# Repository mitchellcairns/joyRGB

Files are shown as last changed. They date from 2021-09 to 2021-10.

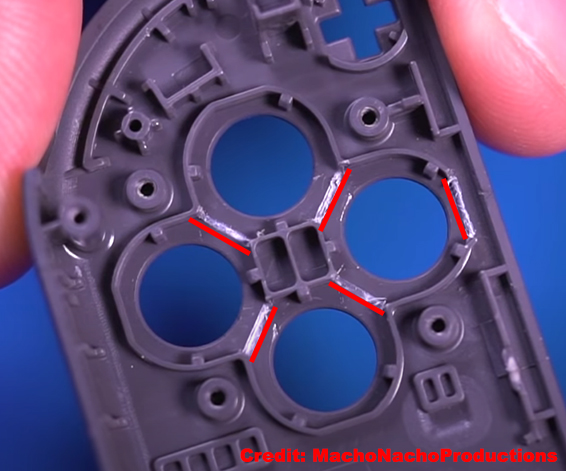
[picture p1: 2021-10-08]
diagrams/RightFrontShellTrim.jpg

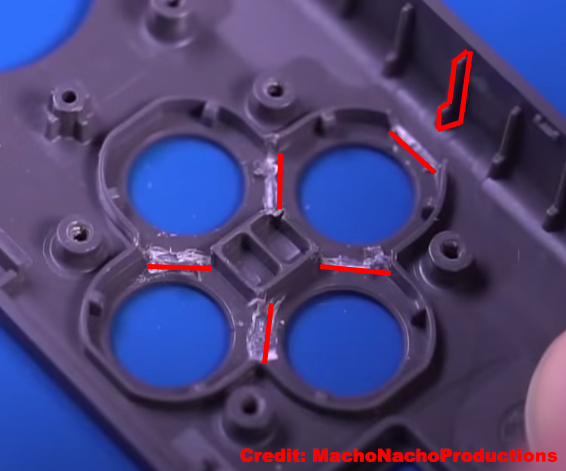
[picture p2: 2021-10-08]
diagrams/LeftFrontShellTrim.jpg

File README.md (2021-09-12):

# joyRGB
Joycon RGB LED kit

See the PDF for info on operating this kit

Features:
- Use the front buttons to control the LED kit
- Full RGB
- Use HEX/HTML Color codes to set up your own presets
- Ability to change color of buttons on the fly
- Rainbow mode
- Auto power on/off
- Brightness control

Install instructions:
- Part 1 - https://www.youtube.com/watch?v=M1x_yPTUGak
- Part 2 - https://www.youtube.com/watch?v=-7K7XvtfKoE
- Part 3 - https://www.youtube.com/watch?v=3CIYKLGDYLE

This Joycon RGB LED project allows the use of individually addressable LEDs to light up the buttons. It does require
trimming the shell, but the end result is a very clean install with little to no light bleed.

While I use hollowed out resin-cast buttons on installs, clear buttons from ExtremeRate will probably also work with some modification.

The rubber pad is replaced with a 3D printed bracket (STL file in this repo) for rigidity underneath the flex PCB. 
The gerber file should be manufactured fairly thin. There's a file for the hardener layer as well to support the pads underneath the
Attiny85 microcontroller.

See the bill of materials for all parts required.

The 10k ohm resistor is used in front of the transistor to control the 'Latch' line on the microcontroller for auto on-off functionality.
330 ohm resistor goes on the LED data line to smooth the signal.

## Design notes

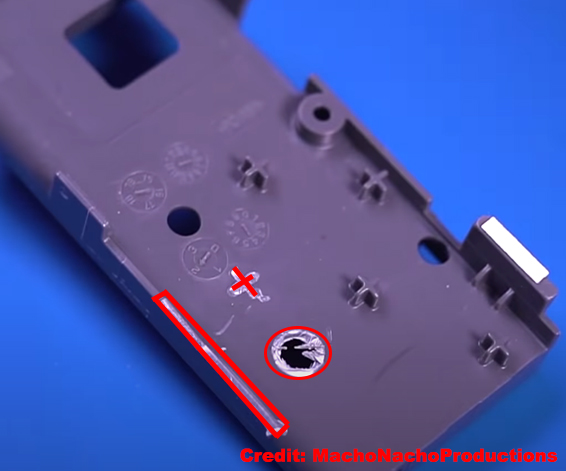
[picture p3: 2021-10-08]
diagrams/LeftTrayTrim.jpg

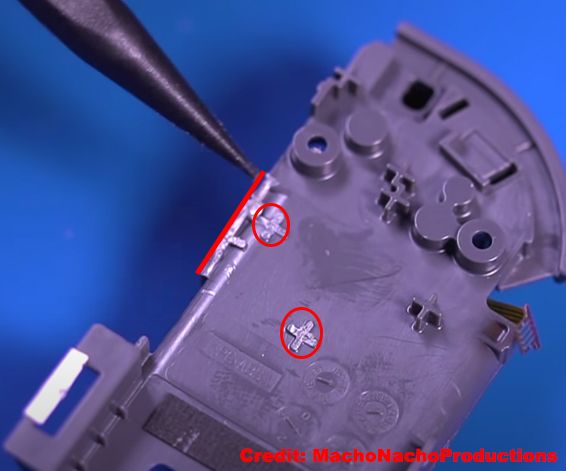
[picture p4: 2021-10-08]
diagrams/RightTrayTrim.jpg

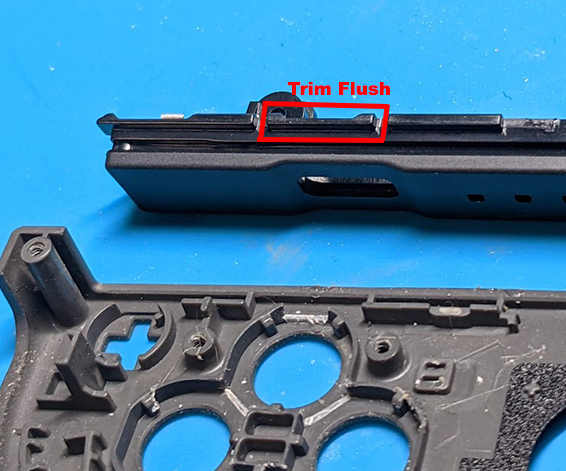
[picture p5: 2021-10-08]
diagrams/RightRailTrim.jpg

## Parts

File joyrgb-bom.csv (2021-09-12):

Item Link | Qty | Item Name
https://www.aliexpress.com/item/32878302621.html?spm=a2g0s.9042311.0.0.12ab4c4d19utiV | 8 | WS2812B-2020 (5mA variant)
https://www.aliexpress.com/item/1005003126067624.html | 2 | ATTINY85-20SU SOP-8
https://www.aliexpress.com/item/1005001436923851.html | 2 | 330 ohm 0603 SMT resistor
https://www.mouser.com/ProductDetail/279-CPF0805F10KC1 | 2 | 10k ohm 0603 SMT resistor
https://www.mouser.com/ProductDetail/78-BAV19WS-HG3-08 | 2 | General purpose Switching Diode SOD-323
https://www.mouser.com/ProductDetail/583-MMBT4401 | 2 | SOT23 NPN Transistor 0.6A 40V

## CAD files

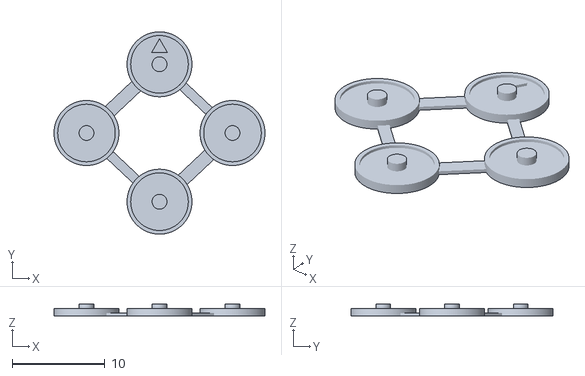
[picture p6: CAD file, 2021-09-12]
JoyconButtonBracket.stl
22.7 x 21.8 x 1.28

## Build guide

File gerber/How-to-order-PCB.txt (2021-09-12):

How to Order PCB

Please refer to:
https://docs.easyeda.com/en/PCB/Order-PCB

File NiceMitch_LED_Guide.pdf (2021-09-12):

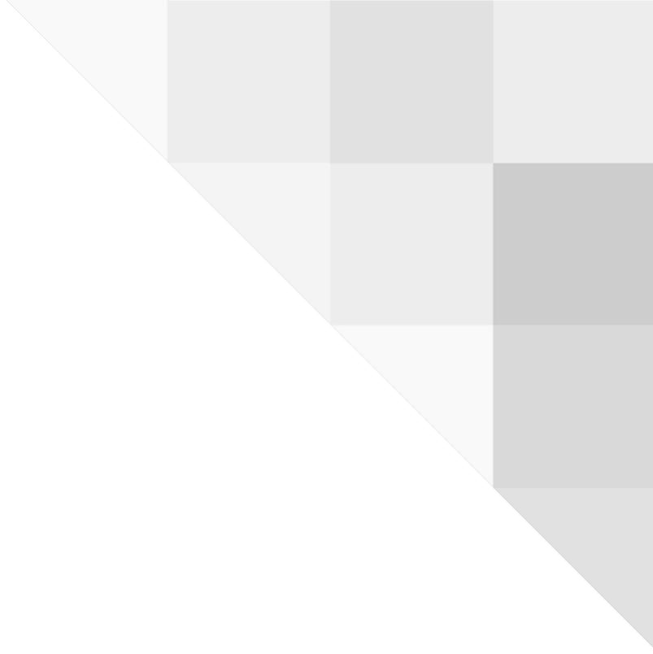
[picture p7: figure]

# Mitch’s JoyCon RGB Mod

# Product Guide

Last Updated July 6, 2021

# 1. Product Controls Overview

In all modes, this product is controlled by pressing a button combination on each JoyCon controller.

On the right JoyCon, this is done by holding the primary button, ‘Plus’, and pressing the secondary button, ‘X’.

On the left JoyCon, this is done by holding the primary button, ‘Minus’, and pressing the secondary button, ‘Up’.

There are two types of inputs-- presses and holds.

A press is performed by holding the primary button, then pressing the second button any number of times.

A hold is performed by holding the primary button, then pressing the second button any number of times, then holding the final press. Keep these directions in mind when reading the guide below and you will be successful in configuring/controlling the LEDs.

# 2. Color Modes

## A. Preset mode -- Built-in color presets B. Solid color mode -- A mode to simply display one color C. Rainbow fade mode -- A mode that fades between all colors continuously

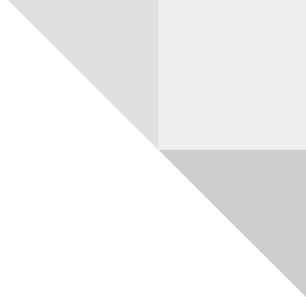
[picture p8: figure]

2

# 3. Device Modes and Controls

## A. Default mode

Upon receiving your JoyCons, the device will be in ‘default’ mode. Here are list of functions you can perform along with the required button inputs:

1. Turn LEDs on/off -- Double press and hold.
2. Decrease brightness -- Double press.
3. Increase brightness -- Triple press.
4. Color mode quick-change -- Triple press then hold.
a. This will cycle between color presets in the following order -- Preset modes, Solid color mode*, Rainbow fade mode.

*If you want to change the color shown in solid color mode, you will need to enter the advanced configuration mode first.

b. Between each color mode change, you will see the lights flash blue twice.
5. Enter advanced configuration mode -- Quadruple press. You will know you’ve entered advanced configuration mode when you see the lights flash teal twice.
6. Enable or Disable display mode -- Quadruple press then hold.
a. If you are enabling display mode, you will see the lights flash orange twice.
b. If the mode is being disabled, you will see the lights flash green twice.

## B. Advanced configuration mode

Depending on which color mode you are in, your configuration options and controls will vary. Please see the table below to understand the configuration options/controls for each color

3

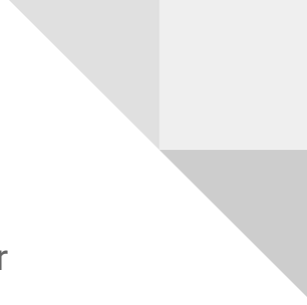
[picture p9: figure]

mode. In advanced configuration mode Press three times to cycle between each of the color modes below. Each time you cycle between a color mode the lights flash blue twice:

1. Preset mode
a. Cycle to the next built-in preset -- Single press.
2. Solid color mode
a. Increase color hue -- Single press.
b. Decrease color saturation -- Double press.
3. Rainbow fade mode
a. Increase color fade speed -- Single press. -- This option loops around after reaching the fastest speed.

In advanced configuration mode, four presses will take you to brightness configuration mode which is the final step before you can save your customizations. You will know you are entering brightness selection mode when you see the lights flash yellow twice.

## C. Brightness configuration mode

This mode simply lets you change the brightness. This is the final setting that needs to be modified before all settings can be saved to the onboard storage.

1. Decrease brightness -- Single press.
2. Increase brightness -- Double press.
3. Save all settings and reboot -- Quadruple press. You will know you have saved all settings when you see the lights flash white twice.

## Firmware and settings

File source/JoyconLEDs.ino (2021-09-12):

#include <FastLED.h>
#include "config.h"
#include <avr/sleep.h>
#include <avr/interrupt.h>
#include <EEPROM.h>

#define LED_COUNT 4
#define COLOR_TIME 50 // Time to fade between colors
#define CHECK_COUNT 5 // How many times to poll buttons for averages
#define BUTTON_THRESHOLD 45 // Value cutoff to determine if button is pressed or not (analog read)
byte SLOWEST_RAINBOW = 26;

// Button states setup
#define NO_PRESS 0
#define RELEASED_PRESS 1
#define HELD_PRESS 2

// Release state setup
#define HELD_START 200
#define HELD_ONE 201
#define HELD_TWO 202
#define HELD_THREE 203


// PIN setup
// ----------------
#define LED_PIN 0
#define aPin A3
#define yPin A2
#define ePin 2
// ----------------
// ----------------

byte SAV_DEBUG = 2;

// Button tracking
// ---------------
bool aPressed = false;
bool yPressed = false;
bool allPressed = false; // true if all buttons pressed
bool finishedHold = true; // Keep track of presses to prevent trailing inputs
byte aValue = 0; // Use to get a button value
byte yValue = 

0; // Use to get y button value
int timer = 0; // store the timer value when counting button presses
int buttonTime = 100; // timer cap
byte buttonPresses = 0; // how many times the button has been pressed
// ----------------
// ----------------

// Color/Brightness setting
// ----------------
byte brightness = 70; // led brightness

bool colorDirty = true; // Set true after changing modes!
bool colorSet = false; // Set true to start a fade!
bool colorInit = false; // Set true after changing and setting up your mode
float colorIncrement = 0; // Used to determine color fade increment (between 0 and 1)

byte colorStep = 15;         // Amount to step up when performing first color selection before going into fine

byte fadeTime = COLOR_TIME; // Time to fade between color ints (1 value at a time) for rainbow modes in ms
byte rainbowTime = 20;

CRGB lastLeds[LED_COUNT]; // Previous color values
CRGB leds[LED_COUNT]; // Current color values
CRGB nextLeds[LED_COUNT]; // Upcoming color values (when fading)
// ----------------
// ----------------

// Mode settings
// ----------------
byte configMode = 0;
#define DEFAULT_MODE    0
#define CONFIG_MODE     1   // Edit general configuration
#define BRIGHTNESS_MODE 2   // Edit brightness for all presets

bool enabled = true;
bool displayMode = true; // If display mode is ON, the LEDs will stay on. 

byte colorMode = 0;
#define COLOR_PRESET     0
#define COLOR_SOLID      1
#define COLOR_RAINBOW    2
byte colorModes = 3;

byte presetSelection = 0;

byte presetCount = 5;
CRGB presets[5][LED_COUNT] = {
  { CRGB::Yellow, CRGB::Green, CRGB::Blue, CRGB:: Red }, //SFC sideways right 
  { CRGB::Green, CRGB::Blue, CRGB::Red, CRGB::Yellow}, // SFC
  { 0xCBCBCB, 0xCBCBCB, 0x41C4C0, 0xEC1328}, // Gamecube - Gray, Gray, Teal, Red
  { 0xE96261, 0xF2CF1A, 0x62CBA1, 0x3E7CCB}, // Dreamcast
  { 0xFFC100, 0xFFC100, CRGB::MediumBlue, CRGB::Green}  // N64
};

CHSV rainbowColor = CHSV(0, 255, 255); // Start with red

UserPreference upref;

// ----------------
// ----------------

void setup() {
  // put your setup code here, to run once:
  delay(100);
  EEPROM.get(0, upref);
  delay(100);
  if (upref.saved == SAV_DEBUG) {
    brightness = upref.brightness;
    colorMode = upref.colorMode;
    rainbowTime = upref.rainbowTime;
    rainbowColor.hue = upref.hue;
    rainbowColor.saturation = upref.saturation;
    presetSelection = upref.presetSelection;
    displayMode = upref.displayMode;
  }
  
  ADMUX = 0x10010000; // Enable internal 2.56v reference
  // FastLED.addLeds<NEOPIXEL, LED_PIN>(leds, LED_COUNT);
  FastLED.addLeds<WS2812B, LED_PIN, RGB>(leds, LED_COUNT);
  FastLED.setBrightness(brightness);
  FastLED.show();

  pinMode(yPin, INPUT);
  pinMode(aPin, INPUT);
  pinMode(ePin, INPUT_PULLUP);
}

void loop() {

  byte butt = buttonCounter();

  idle(butt);

  FastLED.delay(CHECK_COUNT);

  if (!displayMode) {
    if (sleepCheck()) sleep(); // Check to see if we should sleep!
  }
  else {
    delayMicroseconds(400);
  }

}

byte buttonCounter() {

  if (buttonCheck(false) == RELEASED_PRESS) { // When a button is pressed what do we do?
    if (timer == 0 and buttonPresses == 0) { // If we haven't started a timer, lets add a button press and begin adding to the timer.
      timer += 1;
      buttonPresses = 1;
    }
    else if (timer < buttonTime) { // If we are still in the allotted timeframe, add another button press.
      buttonPresses += 1;
    }
  }

  if (timer > 0 and timer < buttonTime) { // If we're in a time loop, do the following
    timer += 1;
  }
  else if (timer >= buttonTime) { // What do we do if the timer is full? We reset the timer, return the button press count and reset that.
    byte toReturn = buttonPresses;
    if (buttonCheck(true) == HELD_PRESS){
      toReturn += HELD_START;
    }
    buttonPresses = 0;
    timer = 0;
    return toReturn;
  }

  // Default return 0
  return 0;
}

byte buttonCheck(bool timeOver) {
  smooth();

  if (aValue >= BUTTON_THRESHOLD) aPressed = true;
  else {
    aPressed = false;
    allPressed = false;
  }

  if (yValue >= BUTTON_THRESHOLD) yPressed = true;
  else {
    yPressed = false;
  }

  if (aPressed and yPressed and !allPressed) {
    allPressed = true;
  }
  else if (allPressed and !yPressed and finishedHold) {
    allPressed = false;
    return RELEASED_PRESS;
  }
  else if (!finishedHold and !yPressed){
    allPressed = false;
    finishedHold = true;
  }
  
  if (allPressed and timeOver) {
    allPressed = false;
    finishedHold = false;
    return HELD_PRESS;
  }

  return NO_PRESS;
}

bool sleepCheck() {
  bool shouldSleep = true;
  for (int i = 0; i < 4; i++){
    int returnValue = digitalRead(ePin);
    if (returnValue == LOW) shouldSleep = false;
  }

  return shouldSleep;
}

void smooth() { // Smooth read of values
  aValue = 0;
  yValue = 0;

  for (byte i = 0; i < CHECK_COUNT; i++) {
    int tempA = analogRead (aPin);
    tempA = analogRead(aPin);
    if ((tempA/4) > aValue) aValue = (tempA/4);
  }
  FastLED.delay(1);
  for (byte i = 0; i < CHECK_COUNT; i++) {
    int tempY = analogRead (yPin);
    tempY = analogRead(yPin);
    if ((tempY/4) > yValue) yValue = (tempY/4);
  }
  FastLED.delay(1);

  // Take an average of all the readings.
  //aValue = aValue / CHECK_COUNT;
  //yValue = yValue / CHECK_COUNT;

}

#define POWER_SWITCH      0
#define SATURATION_CHANGE 1
#define HUE_CHANGE        2
#define BRIGHTNESS_UP     3
#define BRIGHTNESS_DOWN   4
#define COLOR_MODE_CHANGE 5
#define RAINBOW_SPEEDUP   6
#define PRESET_CYCLE      7
#define ENABLE_BRIGHTNESS 11
#define SAVE_ALL          12
#define ENABLE_CONFIG     13
#define MODE_CYCLE        14
#define DISPLAY_MODE      15

void buttonFunction(byte in) {
  if (in == COLOR_MODE_CHANGE) {          // Switch color modes
    colorMode += 1;
    if (colorMode >= colorModes) colorMode = 0;
    if (upref.saved == SAV_DEBUG)
    {
      rainbowColor.hue = upref.hue;
      rainbowColor.saturation = upref.saturation;
    }
    switchIndicator(CRGB::Blue);
    resetColor(false);
  }
  else if (in == POWER_SWITCH) {          // Turn power on/off
    if (enabled) {
      for (byte i = brightness; i > 0; i--) {
        FastLED.setBrightness(i);
        FastLED.show();
        FastLED.delay(5);
      }
      FastLED.clear();
      FastLED.show();
      enabled = false;
    }
    else if (!enabled) {
      for(byte i = 0; i < LED_COUNT; i++) {
        leds[i] = lastLeds[i];
      }
      for (byte i = 1; i <= brightness; i++) {
        FastLED.setBrightness(i);
        FastLED.show();
        FastLED.delay(10);
      }
      enabled = true;
    }
  }
  else if (in == SATURATION_CHANGE) {     // Uptick the saturation
    rainbowColor.saturation -= 20;
    if (rainbowColor.saturation <= 0) rainbowColor.saturation = 255;
    resetColor(colorMode == COLOR_RAINBOW);
  }
  else if (in == HUE_CHANGE) {            // Uptick the hue
    rainbowColor.hue += 15;
    if (rainbowColor.hue >= 255) rainbowColor.hue = 0;
    resetColor(colorMode == COLOR_RAINBOW);
  }
  else if (in == BRIGHTNESS_UP) {         // Uptick brightness
    if (brightness + 20 <= 255) brightness += 20;
    FastLED.setBrightness(brightness);
    FastLED.show();
  }
  else if (in == BRIGHTNESS_DOWN) {       // Downtick brightness
    if (brightness - 20 >= 0) brightness -= 20;
    FastLED.setBrightness(brightness);
    FastLED.show();
  }
  else if (in == RAINBOW_SPEEDUP) {       // Uptick rainbow fade speed
    rainbowTime -= 2;
    if (rainbowTime <= 0) rainbowTime = SLOWEST_RAINBOW;
  }
  else if (in == PRESET_CYCLE) {          // Next item in presets
    presetSelection += 1;
    if (presetSelection >= presetCount) presetSelection = 0;
    resetColor(false);
  }
  else if (in == ENABLE_BRIGHTNESS) {     // Switch to brightness edit mode
    FastLED.setBrightness(brightness);
    FastLED.show();
    configMode = BRIGHTNESS_MODE;
    switchIndicator(CRGB::Yellow);
    resetColor(false);
  }
  else if (in == SAVE_ALL) {              // Save all settings to EEPROM
    upref.hue = rainbowColor.hue;
    upref.saturation = rainbowColor.saturation;
    upref.brightness = brightness;
    upref.colorMode = colorMode;
    upref.rainbowTime = rainbowTime;
    upref.saved = SAV_DEBUG;
    upref.presetSelection = presetSelection;
    upref.displayMode = displayMode;
    EEPROM.put(0, upref);
    delay(100);
    configMode = DEFAULT_MODE;
    switchIndicator(CRGB::White);
    resetColor(false);
  }
  else if (in == ENABLE_CONFIG) {
    configMode = CONFIG_MODE;
    switchIndicator(CRGB::Teal);
    resetColor(false);
  }
  else if (in == MODE_CYCLE) {
    if ( colorMode == COLOR_PRESET ) {
      presetSelection += 1;
      resetColor(false);
      if (presetSelection >= presetCount) 
      {
        presetSelection=0;
        buttonFunction(COLOR_MODE_CHANGE);
      }
    }
    else if ( colorMode == COLOR_SOLID ) {
      buttonFunction(COLOR_MODE_CHANGE);
    }
    else if ( colorMode == COLOR_RAINBOW ) {
      presetSelection = 0;
      buttonFunction(COLOR_MODE_CHANGE);
    }
  }
  else if (in == DISPLAY_MODE) {
    displayMode = !displayMode;
    if (displayMode) switchIndicator(CRGB::Orange);
    else switchIndicator(CRGB::Green);
    
    resetColor(false);
  }
}

void idle(byte pressCount) {
  // COLOR RUNTIME
  if (!colorSet and colorDirty and !colorInit) {    // Only run the mode init if the color is not set and marked dirty. This should only happen once per mode switch
    fadeTime = COLOR_TIME;          // Reset to default on all dirty sets
    if (colorMode == COLOR_PRESET) {
      setNextColors(presets[presetSelection]);
    }
    else if (colorMode == COLOR_SOLID) {
      setNextColor(rainbowColor);
    }
    else if (colorMode == COLOR_RAINBOW and !colorInit) {
      fadeTime = rainbowTime;
      rainbowColor = CHSV(0, 255, 255);
      setNextColor(rainbowColor);
      colorInit = true;
    }
  }
  else if (colorSet and (colorMode == COLOR_RAINBOW) and !colorDirty and colorInit) { // Special rule for rainbow mode
    fadeTime = rainbowTime;
    buttonFunction(HUE_CHANGE);
    setNextColor(rainbowColor);
    colorInit = true;
  }

  if (enabled) colorTick(fadeTime); // perform color tick if the chip is set enable


  // USER INTERFACE
  // --------------
  // 1 and 2 button press options
  if (configMode == CONFIG_MODE and colorMode == COLOR_PRESET) {
    if (pressCount == 1) buttonFunction(PRESET_CYCLE);
  }
  else if ((configMode == CONFIG_MODE and colorMode == COLOR_SOLID)) {
    if (pressCount == 1) buttonFunction(HUE_CHANGE);
    else if (pressCount == 2) buttonFunction(SATURATION_CHANGE);
  }
  else if (configMode == CONFIG_MODE and colorMode == COLOR_RAINBOW) {
    if (pressCount == 1) buttonFunction(RAINBOW_SPEEDUP);
  }

  // 3 button press options
  if (configMode == CONFIG_MODE) {
    if (pressCount == 3) buttonFunction(COLOR_MODE_CHANGE);
  }

  // 4 button press options
  if (configMode == DEFAULT_MODE) {
    if (pressCount == HELD_ONE) buttonFunction(POWER_SWITCH);
    else if (pressCount == HELD_TWO and enabled) buttonFunction(MODE_CYCLE);
    else if (pressCount == HELD_THREE and enabled) buttonFunction(DISPLAY_MODE);
    else if (pressCount == 2 and enabled) buttonFunction(BRIGHTNESS_DOWN);
    else if (pressCount == 3 and enabled) buttonFunction(BRIGHTNESS_UP);
    else if (pressCount == 4 and enabled) buttonFunction(ENABLE_CONFIG);
  }
  else if (configMode == CONFIG_MODE) {
    if (pressCount == 4) buttonFunction(ENABLE_BRIGHTNESS);
  }
  else if (configMode == BRIGHTNESS_MODE) {
    if (pressCount == 1) buttonFunction(BRIGHTNESS_DOWN);
    else if (pressCount == 2) buttonFunction(BRIGHTNESS_UP);
    else if (pressCount == 4) buttonFunction(SAVE_ALL);
  }
  // -------------
  // -------------
  // END USER INTERFACE

}

void setNextColors(CRGB colors[LED_COUNT]) {
  for (byte i = 0; i < LED_COUNT; i++) {
    lastLeds[i] = leds[i];
    nextLeds[i] = colors[i];
  }
  resetColor(false);
}

void setNextColor(CRGB color) {
  for (byte i = 0; i < LED_COUNT; i++) {
    lastLeds[i] = leds[i];
    nextLeds[i] = color;
  }
  resetColor(colorMode==COLOR_RAINBOW);
}

void colorTick(float changeTime) { // Handle fading between colors for transition purposes
  if (colorDirty and !colorSet) {

    colorIncrement += (255 / changeTime);
    byte inc = (byte) colorIncrement;

    for (byte i = 0; i < LED_COUNT; i++) { // Set the next color on all LEDs blended
      leds[i] = blend(lastLeds[i], nextLeds[i], inc);
    }

    if (inc >= 255) { // If the fade is complete, reset the increment and set as not dirty!
      for (byte i = 0; i < LED_COUNT; i++) {
        leds[i] = nextLeds[i]; // Set all colors to their final form
      }
      colorIncrement = 0;
      colorDirty = false; // Unmark that the color is dirty
      colorSet = true; // Mark that the color has been 'set'.
    }

  }
  FastLED.show(); // Send update to LEDs
}

void resetColor(bool init) {
  colorDirty = true;
  colorSet = false;
  colorInit = init;
}

void switchIndicator(CRGB col) {

  for (byte i = 0; i < 2; i++)
  {
    fill_solid(leds, LED_COUNT, col);
    FastLED.show();
    delay(500);
    FastLED.clear();
    FastLED.show();
    delay(500);
  }
}

void sleep() {
  configMode = DEFAULT_MODE;
  enabled = true;
  buttonFunction(POWER_SWITCH);
  
  set_sleep_mode(SLEEP_MODE_PWR_DOWN);
  sleep_enable();
  attachInterrupt(0,wakeUp,LOW);
  sleep_mode();
  sleep_disable();
  detachInterrupt(0);
  enabled = false;
  buttonFunction(POWER_SWITCH);

} // sleep

void wakeUp() {}

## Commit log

2021-09-12 Added button bracket STL
    [JoyconButtonBracket.stl]
2021-09-12 Bill of materials added
    [joyrgb-bom.csv]
2021-09-12 Fixed 10k resistor link in bom
    [joyrgb-bom.csv]
2021-09-17 Added solder point diagram
